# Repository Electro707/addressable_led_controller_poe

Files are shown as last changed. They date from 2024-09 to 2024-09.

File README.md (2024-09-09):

# Addressable LED Strip Controller, POE Version
#### Rev 3 (see notes)

This is the repository for my LED strip controller. This LED controller is capable of controlling any addressable LED strip (1 or two data wires).

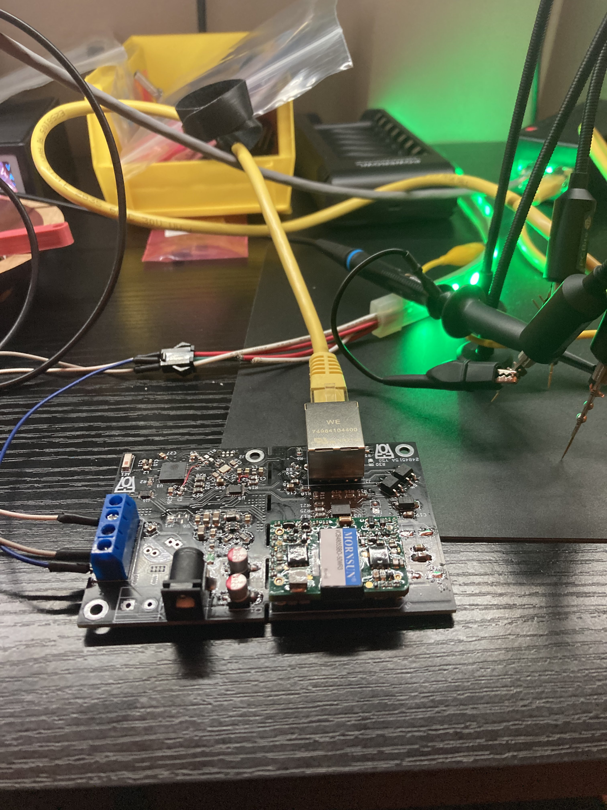
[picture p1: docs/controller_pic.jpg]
Image of Controller


## Hardware Bugs

The following hardware bug exists with this version of the PCB, which will be addessed in the next revision:
- The LED data pin, IO35, is input only. Use IO32/CLK for now.
- The traces to IO16, IO17 are connected to something. Must have trace cut out.
- `E_INT` must be connected to GP0, and disconnected from IO18
- `E_RST` should be pulled down, not up
- `LED2` should have a dedicated pulldown resistor.
- The PHY chip will oscillate even if RESET is held low. Thus to turn on the strip, one must reset the ESP32 randomly until it boots

## Firmware

This controller uses the [WLED firmware](https://github.com/Aircoookie/WLED). Instructions to upload the firmware unto the board can be found on their webpage.

For this revision, there is a modified version of WLED to enable Ethernet. The diff is in [docs/rev3_patch.diff](docs/rev3_patch.diff), which is applied to commit `1dab26bcbcac051f2b7be47a2d5c757a9938bf1f`

Thru J2, you can connect an ESP32 programmer such as the ESP-Prog. You can also make your own "automatic downloader" (i.e not requiring to reset the device and selecting boot mode when uploading) circuit. Details of which can be found on Espressif's ESP-Prog docs on [Automatic Downloading Function](https://espressif-docs.readthedocs-hosted.com/projects/espressif-esp-iot-solution/en/latest/hw-reference/ESP-Prog_guide.html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).

## Revisioning

This version was originally a continuation of my original LED controller, over at [https://github.com/Electro707/addressable_led_controller](https://github.com/Electro707/addressable_led_controller), where it was given a Rev 3 revision.

Since then, I have made another smaller non-POE controller, and thus decided to split this project into it's own repository. And thus Rev 1 and 2 does not exist for this variant, and everything starts from Rev 3.

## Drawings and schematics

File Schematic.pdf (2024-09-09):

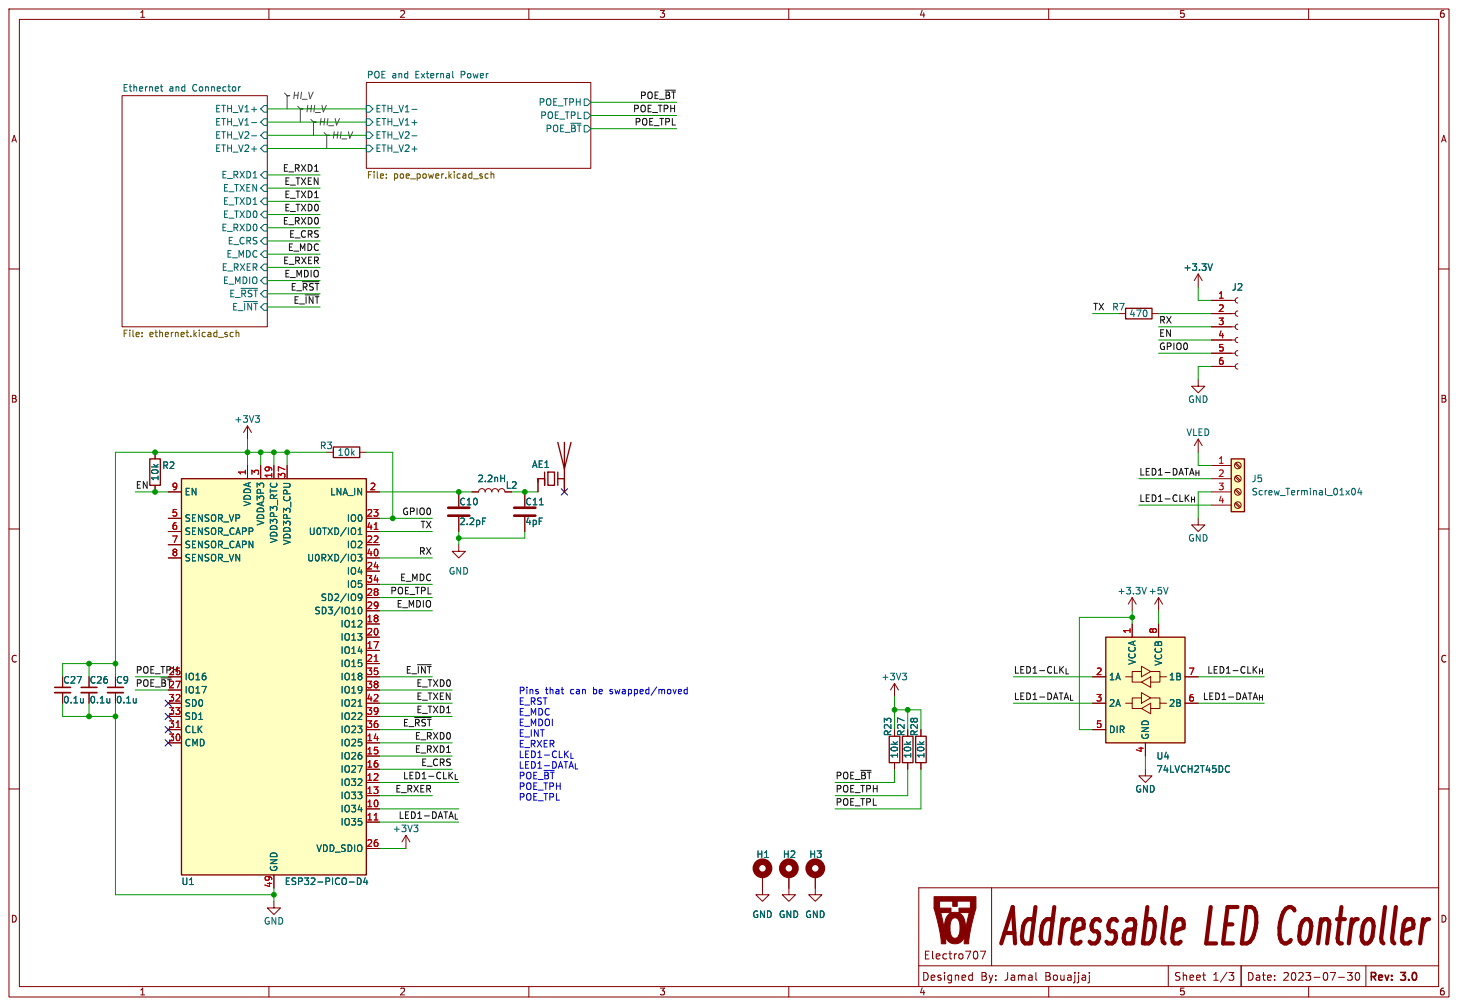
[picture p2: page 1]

Pins that can be swapped/moved E_RST E_MDC

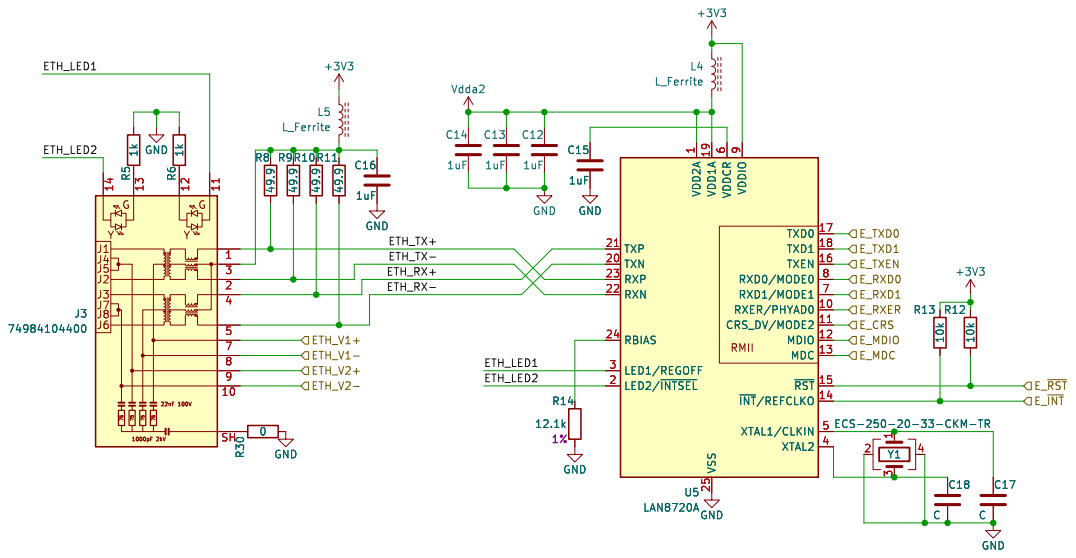
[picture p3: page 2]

1 RXER/PHYAD0 10 CRS_DV/MODE2 11 MDIO 12 MDC 13 ~{INT}/REFCLKO14 ~{RST} 15 TXEN 16 TXD0 17 TXD1 18 VDD1A 19

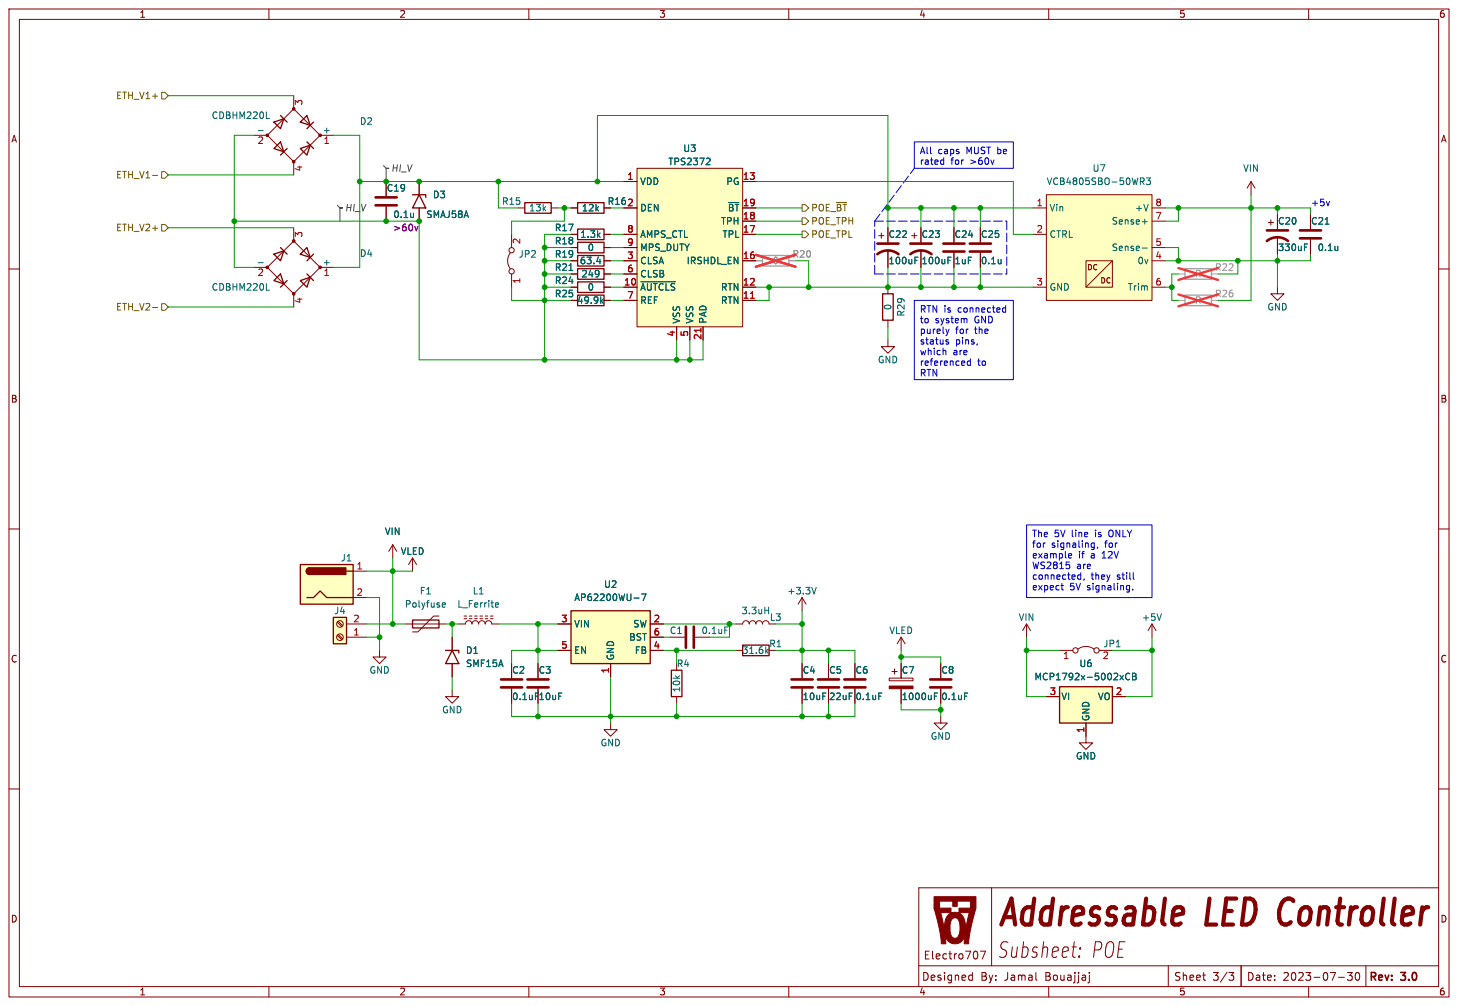
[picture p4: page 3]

All caps MUST be

to system GND
purely for the
status pins, which are

1 SW 2 VIN 3 FB 4 EN 5 BST 6 U2 AP62200WU-7

1 SW 2 VIN 3 FB 4 EN 5 BST 6 D1SMF15A C2

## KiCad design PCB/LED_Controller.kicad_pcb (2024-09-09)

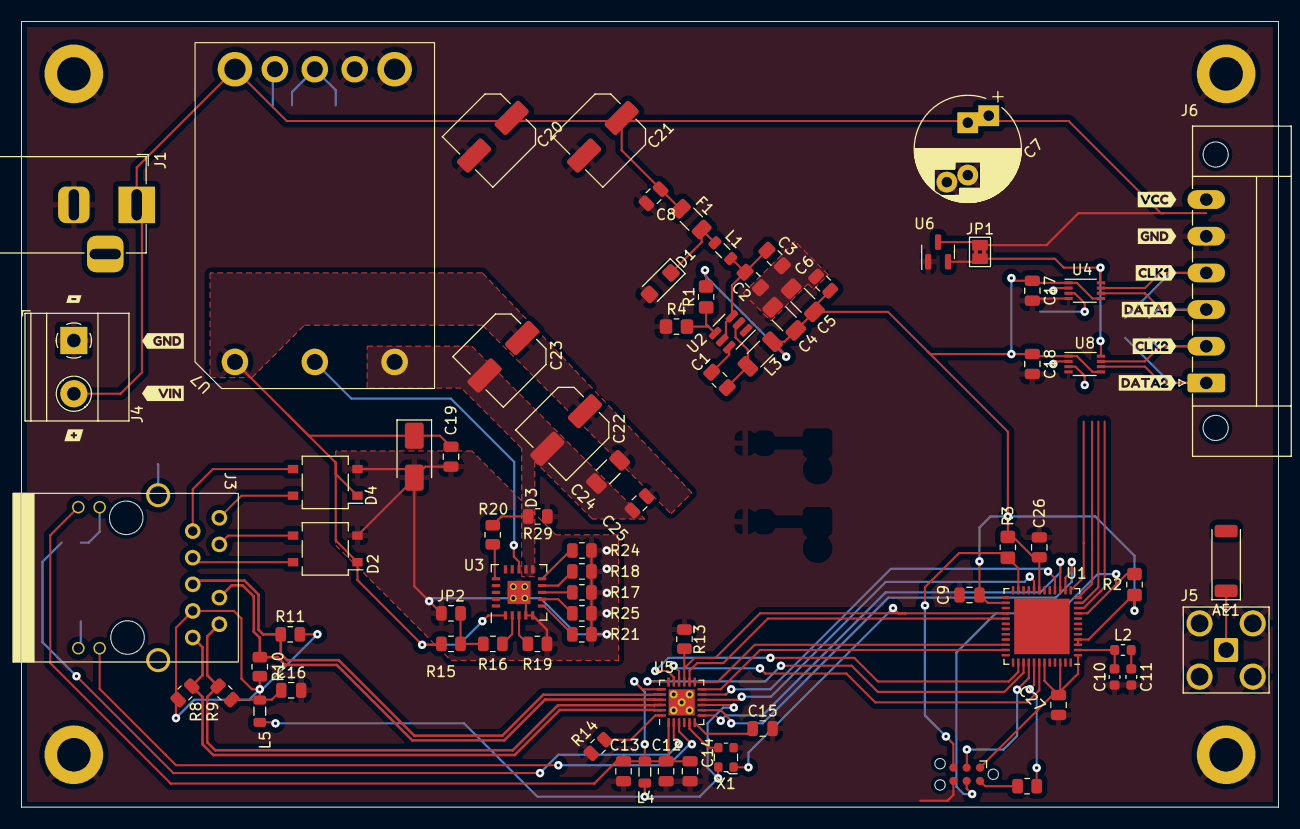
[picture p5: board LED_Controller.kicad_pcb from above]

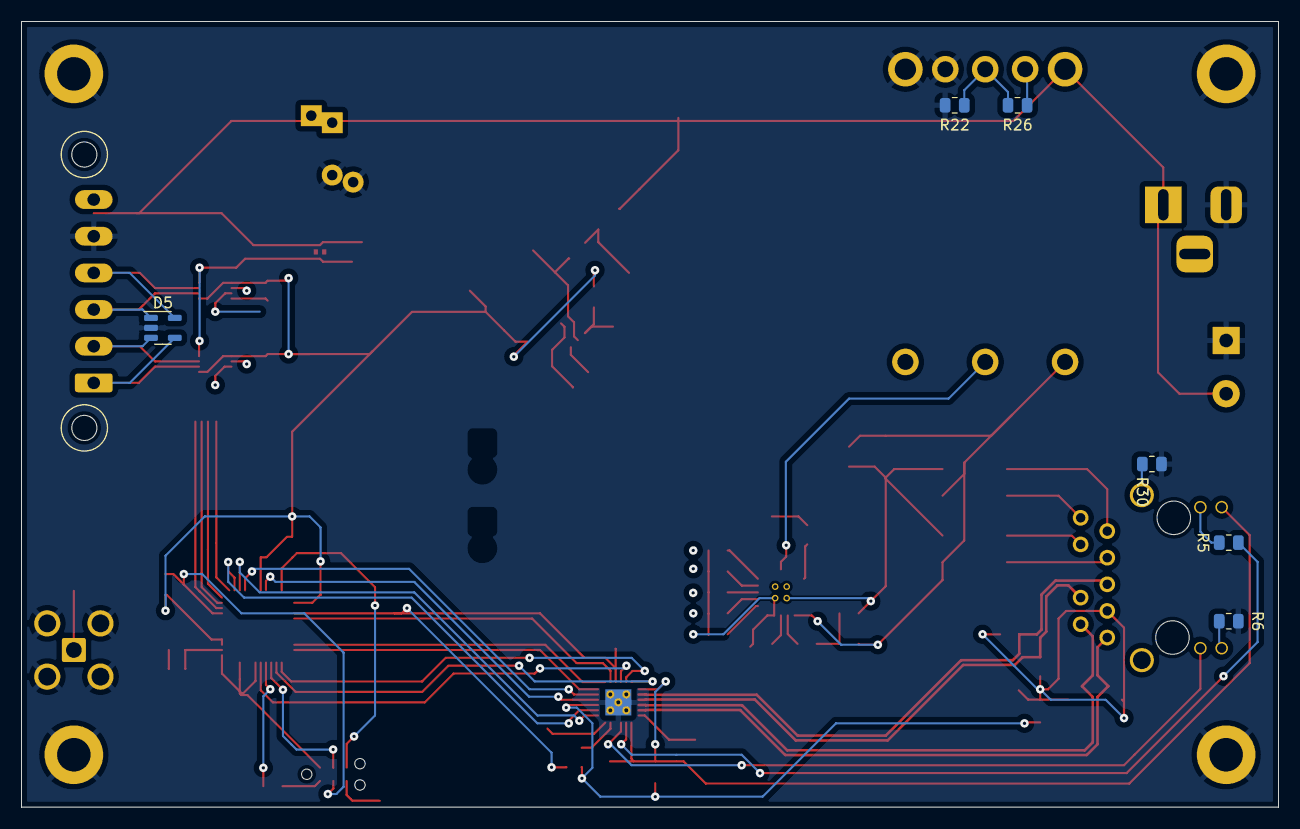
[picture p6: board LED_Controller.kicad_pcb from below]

Board: 2 copper layers, 120.0 x 75.0 mm, 96 parts (6 on the bottom side), 63 nets.

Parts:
AE1: Antenna_Chip; Johanson_2450AT43F0100
C1, C2: 0.1uF; C_0805_2012Metric_Pad1.18x1.45mm_HandSolder
C3: 10uF; C_0805_2012Metric_Pad1.18x1.45mm_HandSolder
C4: 10uF; C_1206_3216Metric_Pad1.33x1.80mm_HandSolder
C5: 22uF; C_1206_3216Metric_Pad1.33x1.80mm_HandSolder
C6, C8: 0.1uF; C_0805_2012Metric
C7: 1000uF; CP_Radial_D10.0mm_P5.00mm_P7.50mm
C9, C17, C18, C19, C25, C26, C27: 0.1u; C_0805_2012Metric
C10: 2.2pF; C_0603_1608Metric
C11: 4pF; C_0603_1608Metric
C12, C13, C14, C15, C16: 1uF; C_0805_2012Metric
C20: 330uF; C_Elec_6.3x5.4
C21: 0.1u; C_Elec_6.3x5.4
C22: 100uF; C_Elec_6.3x5.4
C23: 100uF; C_Elec_6.3x5.8
C24: 1uF; C_1206_3216Metric_Pad1.33x1.80mm_HandSolder
D1: SMF15A; D_SMF
D2, D4: CDBHM220L; TO-269AA
D3: SMAJ58A; D_SMA
D5: SP0504BAHT; SOT-23-5
F1: Polyfuse; Fuse_1206_3216Metric
H1, H2, H3, H4: MountingHole_Pad; MountingHole_3.2mm_M3_DIN965_Pad
J1: Barrel_Jack; BarrelJack_Horizontal
J2: Conn_01x06_Female; Tag-Connect_TC2030-IDC-NL_2x03_P1.27mm_Vertical
J3: 74984104400
J4: Screw_Terminal_01x02; TerminalBlock_Phoenix_MKDS-1,5-2-5.08_1x02_P5.08mm_Horizont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
J5: Conn_Coaxial; SMA_Amphenol_901-143_Horizontal
J6: Screw_Terminal_01x06; PhoenixContact_MC_1,5_6-GF-3.5_1x06_P3.50mm_Horizontal_Thre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
JP1: Jumper_2_Bridged; SolderJumper-2_P1.3mm_Bridged2Bar_Pad1.0x1.5mm
JP2: Jumper_2_Bridged; R_0805_2012Metric
L1, L4, L5: L_Ferrite; L_0805_2012Metric
L2: 2.2nH; L_0603_1608Metric
L3: 3.3uH; L_1206_3216Metric_Pad1.22x1.90mm_HandSolder
R1: 31.6k; R_0805_2012Metric_Pad1.20x1.40mm_HandSolder
R2, R3, R4: 10k; R_0805_2012Metric_Pad1.20x1.40mm_HandSolder
R5, R6: 1k; R_0805_2012Metric
R7: 470; R_0805_2012Metric
R8, R9, R10, R11: 49.9; R_0805_2012Metric
R13: 10k; R_0805_2012Metric
R14: 12.1k; R_0805_2012Metric
R15: 13k; R_0805_2012Metric
R16: 12k; R_0805_2012Metric
R17: 1.3k; R_0805_2012Metric
R18, R20, R24, R29, R30: 0; R_0805_2012Metric
R19: 63.4; R_0805_2012Metric
R21: 249; R_0805_2012Metric
R22, R26: R; R_0805_2012Metric
R25: 49.9k; R_0805_2012Metric
U1: ESP32-PICO-D4; QFN-48-1EP_7x7mm_P0.5mm_EP5.3x5.3mm
U2: AP62200WU-7; TSOT-23-6
U3: TPS2372; TI_RGW0020B
U4, U8: 74LVCH2T45DC; VSSOP-8_2.3x2mm_P0.5mm
U5: LAN8720A; VQFN-24-1EP_4x4mm_P0.5mm_EP2.5x2.5mm_ThermalVias
U6: MCP1792x-5002xCB; SOT-23
U7: VCB4805SBO-50WR3
X1: ECS-2520MV-xxx-xx; Oscillator_SMD_ECS_2520MV-xxx-xx-4Pin_2.5x2.0mm
kibuzzard-64D45DDA: G***; kibuzzard-64D45DDA
kibuzzard-6599B9E0: G***; kibuzzard-6599B9E0
kibuzzard-6599B9EA: G***; kibuzzard-6599B9EA
kibuzzard-6599B9F1: G***; kibuzzard-6599B9F1
kibuzzard-6599BA4A: G***; kibuzzard-6599BA4A
kibuzzard-6599BA32: G***; kibuzzard-6599BA32
kibuzzard-6599BA38: G***; kibuzzard-6599BA38
kibuzzard-6599BAF9: G***; kibuzzard-6599BAF9
kibuzzard-6599BB04: G***; kibuzzard-6599BB04
kibuzzard-6599BB10: G***; kibuzzard-6599BB10

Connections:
+3V3: C4.1, C5.1, C6.1, C9.1, C17.1, C18.1, C26.1, C27.1, J2.1, L3.2, L4.2, L5.2, R1.2, R2.1, R3.1, U1.1 (VDDA), U1.3 (VDDA3P3), U1.4 (VDDA3P3), U1.19 (VDD3P3_RTC), U1.26 (VDD_SDIO), U1.37 (VDD3P3_CPU), U1.43 (VDDA), U1.46 (VDDA), U4.1 (VCCA), U4.5 (DIR), U5.9 (VDDIO), U8.1 (VCCA), U8.5 (DIR), X1.4 (VDD)
+5V: JP1.2 (B), U4.8 (VCCB), U6.2 (VO), U8.8 (VCCB)
/EN: J2.4, R2.2, U1.9 (EN)
/E_CRS_DV: U1.16 (IO27), U5.11 (CRS_DV/MODE2)
/E_MDC: U1.34 (IO5), U5.13 (MDC)
/E_MDIO: U1.35 (IO18), U5.12 (MDIO)
/E_RXD0: U1.14 (IO25), U5.8 (RXD0/MODE0)
/E_RXD1: U1.15 (IO26), U5.7 (RXD1/MODE1)
/E_RXER: U1.20 (IO13), U5.10 (RXER/PHYAD0)
/E_TXD0: U1.38 (IO19), U5.17 (TXD0)
/E_TXD1: U1.39 (IO22), U5.18 (TXD1)
/E_TXEN: U1.42 (IO21), U5.16 (TXEN)
/E_~INT: U1.29 (SD3/IO10), U5.14 (~INT/REFCLKO)
/E_~RST: R13.2, U1.28 (SD2/IO9), U5.15 (~RST), X1.1 (Tri-State)
/Ethernet and Connector/ETH_LED1: J3.11, U5.3 (LED1/REGOFF)
/Ethernet and Connector/ETH_LED2: R5.2, U5.2 (LED2/~INTSEL)
/Ethernet and Connector/ETH_RX+: J3.4 (RD+), R10.2, U5.21 (TXP)
/Ethernet and Connector/ETH_RX-: J3.5 (RD-), R11.2, U5.20 (TXN)
/Ethernet and Connector/ETH_TX+: J3.1 (TD+), R8.2, U5.23 (RXP)
/Ethernet and Connector/ETH_TX-: J3.2 (TD-), R9.2, U5.22 (RXN)
/Ethernet and Connector/ETH_V1+: D2.4, J3.7 (V1+)
/Ethernet and Connector/ETH_V1-: D2.3, J3.8 (V1-)
/Ethernet and Connector/ETH_V2+: D4.3, J3.9 (V2+)
/Ethernet and Connector/ETH_V2-: D4.4, J3.10 (V2-)
/GPIO0: J2.5, R3.2, U1.23 (IO0), U5.5 (XTAL1/CLKIN), X1.3 (OUT)
/LED1-CLK_{H}: D5.5 (K), J6.4, U4.7 (1B)
/LED1-CLK_{L}: U1.12 (IO32), U4.2 (1A)
/LED1-DATA_{H}: D5.1 (K), J6.3, U4.6 (2B)
/LED2-CLK_{H}: D5.3 (K), J6.2, U8.7 (1B)
/LED2-DATA_{H}: D5.4 (K), J6.1, U8.6 (2B)
/RX: J2.3, U1.40 (U0RXD/IO3)
/TX: R7.1, U1.41 (U0TXD/IO1)
GND: C2.2, C3.2, C4.2, C5.2, C6.2, C7.2, C8.2, C9.2, C10.2, C11.2, C12.2, C13.2, C14.2, C15.2, C16.2, C17.2, C18.2, C20.2, C21.2, C26.2, C27.2, D1.2 (A2), D5.2 (A), H1.1, H2.1, H3.1, H4.1, J1.2, J2.6, J4.1, J5.2 (Ext), J6.5, R4.1, R6.2, R13.1, R14.2, R22.1, R29.1, R30.2, U1.49 (GND), U2.1 (GND), U4.4 (GND), U5.25 (VSS), U6.1 (GND), U7.4 (0v), U7.5 (Sense-), U8.4 (GND), X1.2 (GND)
unnamed: AE1.1 (FEED), C11.1, J5.1 (In), L2.2
unnamed: D1.1 (A1), F1.2, L1.1
unnamed: C19.1, C22.1, C23.1, C24.1, C25.1, D2.1 (+), D3.1 (A1), D4.1 (+), R15.1, U3.1 (VDD), U7.1 (Vin)
unnamed: C19.2, D2.2 (-), D3.2 (A2), D4.2 (-), JP2.1 (A), R17.1, R18.1, R19.1, R21.1, R24.1, R25.1, U3.4 (VSS), U3.5 (VSS), U3.21 (PAD)
unnamed: J2.2, R7.2
unnamed: C16.1, J3.3 (CD), L5.1, R8.1, R9.1, R10.1, R11.1
unnamed: J3.12, R6.1
unnamed: J3.13, R5.1
unnamed: J3.SH, R30.1
unnamed: JP2.2 (B), R15.2, R16.1
unnamed: C10.1, L2.1, U1.2 (LNA_IN)
unnamed: C1.1, U2.6 (BST)
unnamed: C2.1, C3.1, L1.2, U2.3 (VIN), U2.5 (EN)
unnamed: R1.1, R4.2, U2.4 (FB)
unnamed: C1.2, L3.1, U2.2 (SW)
unnamed: R17.2, U3.8 (AMPS_CTL)
unnamed: R19.2, U3.3 (CLSA)
unnamed: R21.2, U3.6 (CLSB)
unnamed: R16.2, U3.2 (DEN)
unnamed: R20.1, U3.16 (IRSHDL_EN)
unnamed: R18.2, U3.9 (MPS_DUTY)
unnamed: U3.13 (PG), U7.2 (CTRL)
unnamed: R25.2, U3.7 (REF)
unnamed: R24.2, U3.10 (~AUTCLS)
unnamed: R14.1, U5.24 (RBIAS)
unnamed: C15.1, U5.6 (VDDCR)
unnamed: C22.2, C23.2, C24.2, C25.2, R20.2, R29.2, U3.11 (RTN), U3.12 (RTN), U7.3 (GND)
unnamed: R22.2, R26.2, U7.6 (Trim)
VIN: C7.1, C8.1, C20.1, C21.1, F1.1, J1.1, J4.2, J6.6, JP1.1 (A), R26.1, U6.3 (VI), U7.7 (Sense+), U7.8 (+V)
Vdda2: C12.1, C13.1, C14.1, J3.14, L4.1, U5.1 (VDD2A), U5.19 (VDD1A)

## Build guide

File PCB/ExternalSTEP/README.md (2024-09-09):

# External 3D Models
The 3D models in this folder are all made by the manufacturer. As such, I have not included them in the git release to not deal with licensing issues.

If you would like to have the 3D models, you must download them for the manufacturer. I have listed all of what are used in the next section, as well as how to get them.

## Model List
- VCB48_SBO-50WR3.stp: https://www.mornsun-power.com/html/products-detail/VCB48_SBO-50WR3%28-N%29.html
- Download_STP_74984104400 (rev1).stp: https://www.we-online.com/en/components/products/WE-LAN-RJ45_THR
